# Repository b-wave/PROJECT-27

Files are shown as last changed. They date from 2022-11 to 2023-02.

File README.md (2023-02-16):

# PROJECT-27
Which was a Telemetering transmitter from the 1964 era book **103 Simple Transistor Projects**, by Tom Knitel  I grew up with this book and this was one of my bucket-list projects from it. Although I am *not exactly sure* how my pre-teen self planned to send this device aloft.  I do remember trying to build it up with a CB radio crystal and a few random transistors (it never worked) and had some vague idea of 20 or so toy helium balloons in a laundry bag! Informaton from this transmitter is not sent digitally from this device either.  The RF is AM modulated and the frequency of the modulation is controlled by a thermistor.  Of course, this would need to be calibrated to make any sense of the data. 

For more details on my check out my site: (https://brainwave57.blogspot.com/2022/11/project-27-part-1.html)

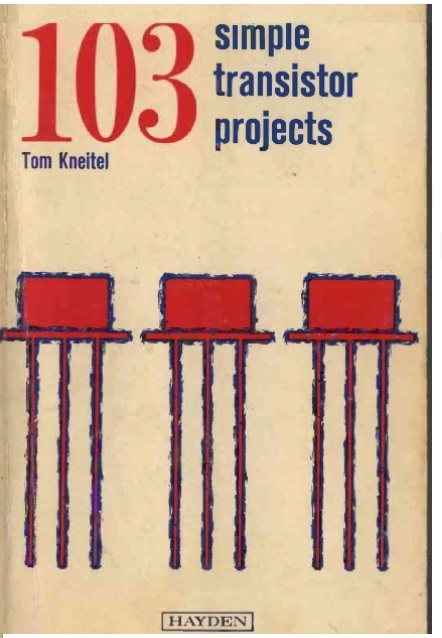
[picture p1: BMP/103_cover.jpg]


103 Projects!

I created two versions, MKI and MKIII are functional. The MK1 is pretty much a copy of the original version. The Mk3 may actually be legal to operate as a telemetering device on the current 27-MHz band. The MK3 is a modern version that also features the same simple Temperature-to-Frequency converter it also now includes a way to include altitude information encoded in the length of the tone burst (Pulse modulated) and even a bright LED beacon.  I thought I had some of the original Ge Transistors, but it turned out they were really old-style Si devices. I found sources for the original transistors online but at a cost that did not make it practical to try or even risk these antique transistors to this experiment... Even buying the Over Tone crystals is costly. I did find a solution for both.  

They are built without any Germanium or PNP transistors. 

The files here are "modern" versions of the **#27 Telemetering Transmitter**. Basically, the first version was a simple crystal oscillator and a multivibrator circuit - just like the original. The crystal was taken from a toy "27MHZ" remote controller. It turns out the frequency is in the ISM telemetry part of that band. The original project #27 goes into detail about the FCC requirements, in force in 1964. He even recommends the transmitter is inspected by a certified person to comply with the then requirements. I did a quick search of the FCC rules and found the mentioned sections are not even in existence. I did see the current requirements have differences are that more power is apparently now allowed - but - there is now a limit now on the length of time a "tone" can be transmitted. The original and MK1 transmit continuously so they would definitely not be legal. But of course, none of these transmitters are FCC type accepted for manufacture but for experimental purposes on the ISM band it should be OK.

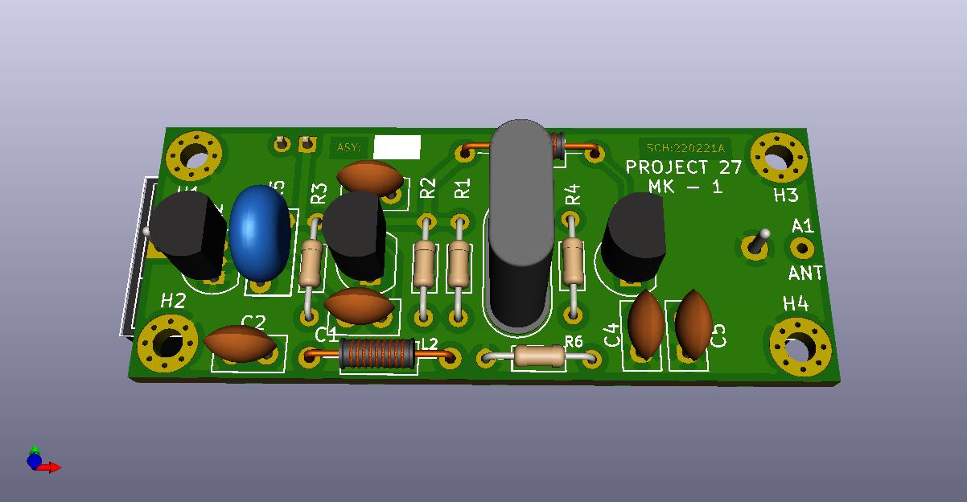
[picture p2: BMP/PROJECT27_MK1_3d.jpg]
PROJECT-27

Telemetering Tranmiter Version MK1 3D View

That's why the new Mk3 version.  It attempts to limit the time that the tone is transmitted and clean up the output to hopefully comply with the rules.  The original seems to rely on low power and the antenna length to limit the spurious emissions surely caused by a 3rd overtone crystal oscillator.  The timing circuit was implemented as another two-transistor multivibrator. Since it originally started life as a "Flashing beacon" in the same book -- I also added a high efficiency LED that produces a bright strobe beacon as well so it can be tracked and possibly help find it.  Since the strobes timing was arbitrarily set, I realized that that could be, in fact, controlled and a second channel of information could be transmitted by this pulse length.  I then constructed a 1960's technology version of an altimeter that is a simple sealed tube of air with a plunger attached to a slide potentiometer. I will add details of this device later. (Mk2 was a never completed high(er) power version)

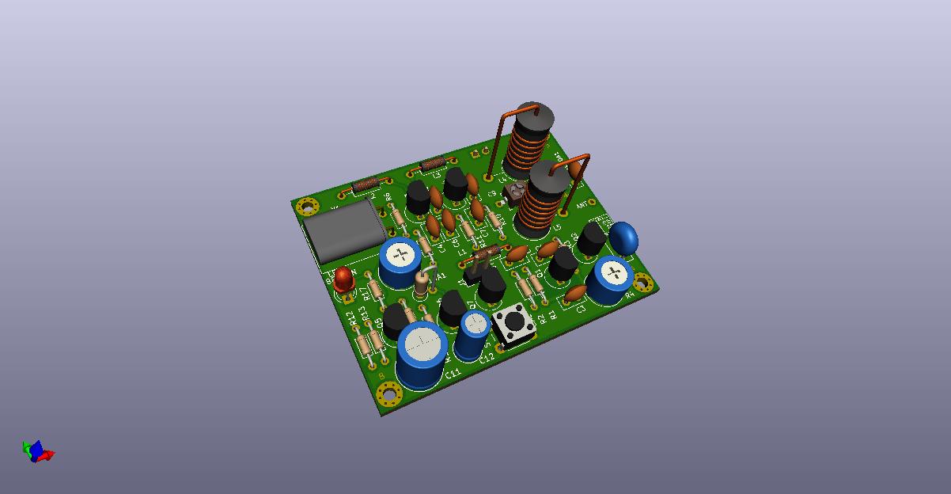
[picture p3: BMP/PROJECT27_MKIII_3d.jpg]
PROJECT-27

Telemetering Tranmitter Version MK3 (Top 3D View)

The original was intended to powered only by 1.5V AA cell.  Three volts would actually be OK for FCC power output requirements. I think a modern LiPo would probably survive the extreme cold a balloon-borne sonde would encounter. There is now plenty of room for two cells as shown on the bottom view. Of course, weight is a prime consideration for balloon payloads as well so LiPo may be best.  

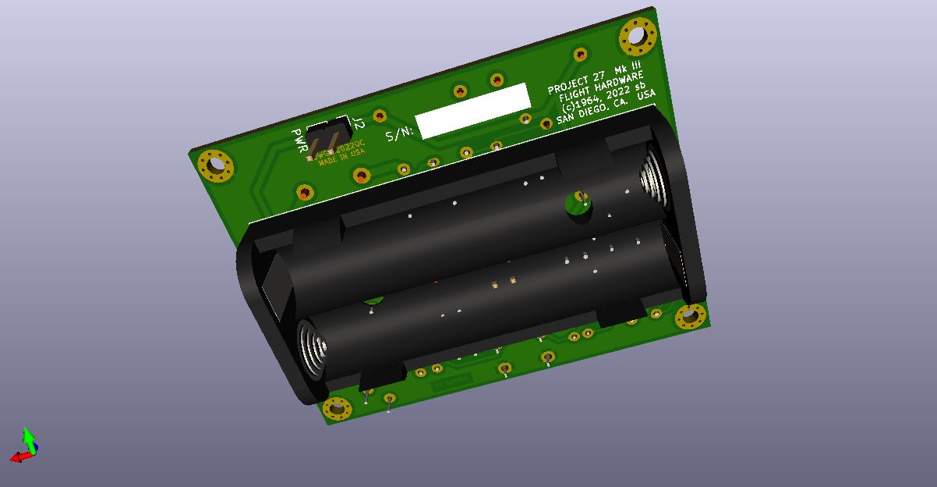
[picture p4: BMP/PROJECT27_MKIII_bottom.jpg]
PROJECT-27

Tranmitter Version MK3 (Bottom 3D View)

I doubt if this thing ever did fly on a balloon to or will my version but it was a fun pandemic project just to see it work. 

#Circuit boards are availble on:

MKI  Board: https://oshpark.com/shared_projects/9dS7OwyD

MKII Board:  **Never Finished** 

MKIII Board: https://oshpark.com/shared_projects/CLHAeEab

Cheers!

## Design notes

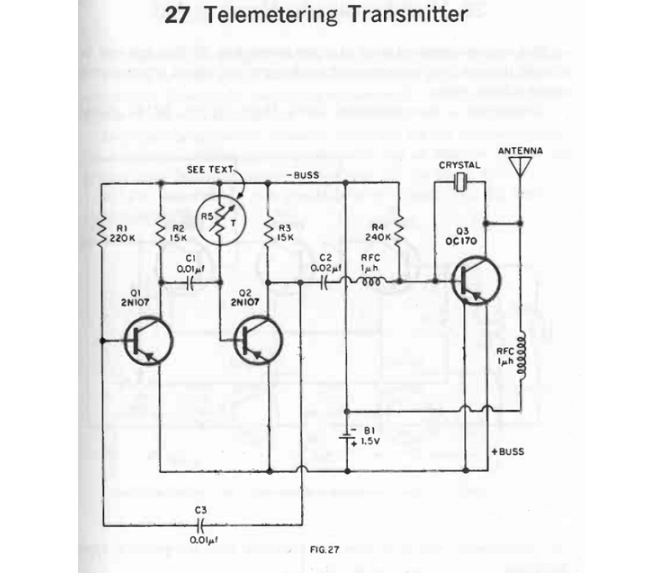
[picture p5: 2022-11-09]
BMP/Proj27_sch.png

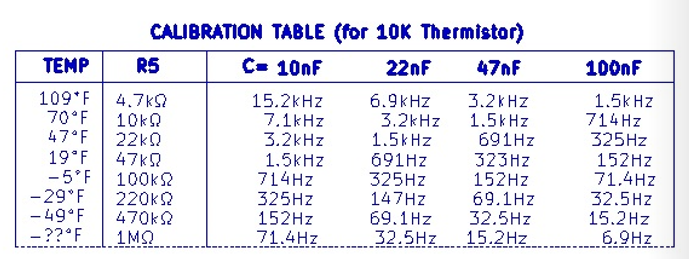
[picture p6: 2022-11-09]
BMP/proj27_cal.png

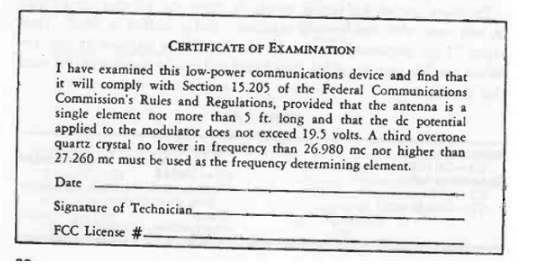
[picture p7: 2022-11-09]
BMP/proj27-cirtif.png

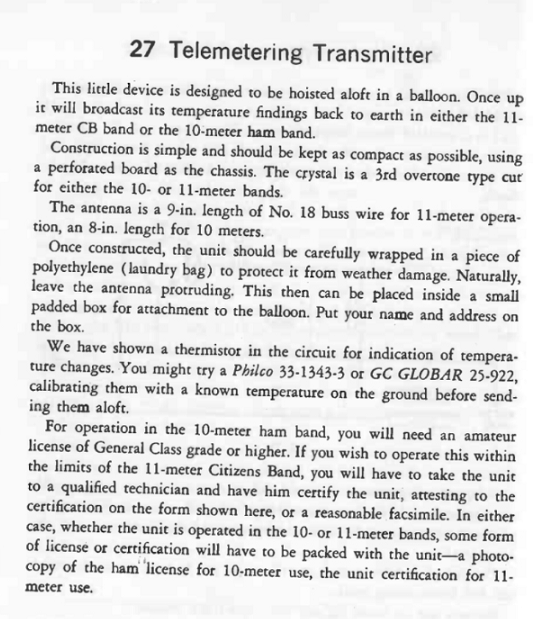
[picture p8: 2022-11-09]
BMP/Proj27_Text.png

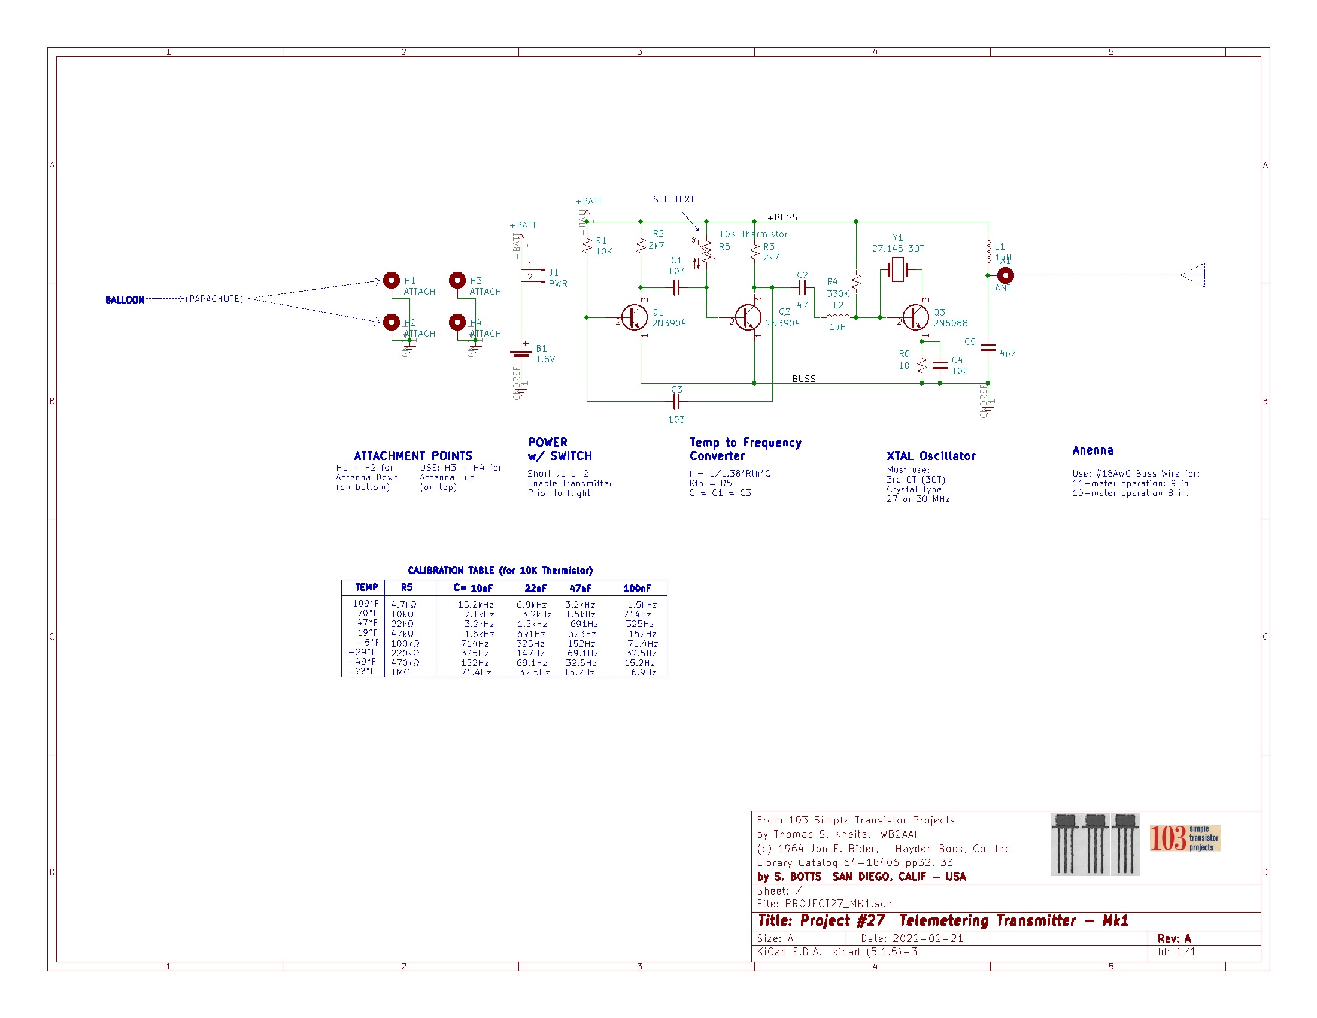
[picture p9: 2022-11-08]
BMP/project27_MK1.jpg

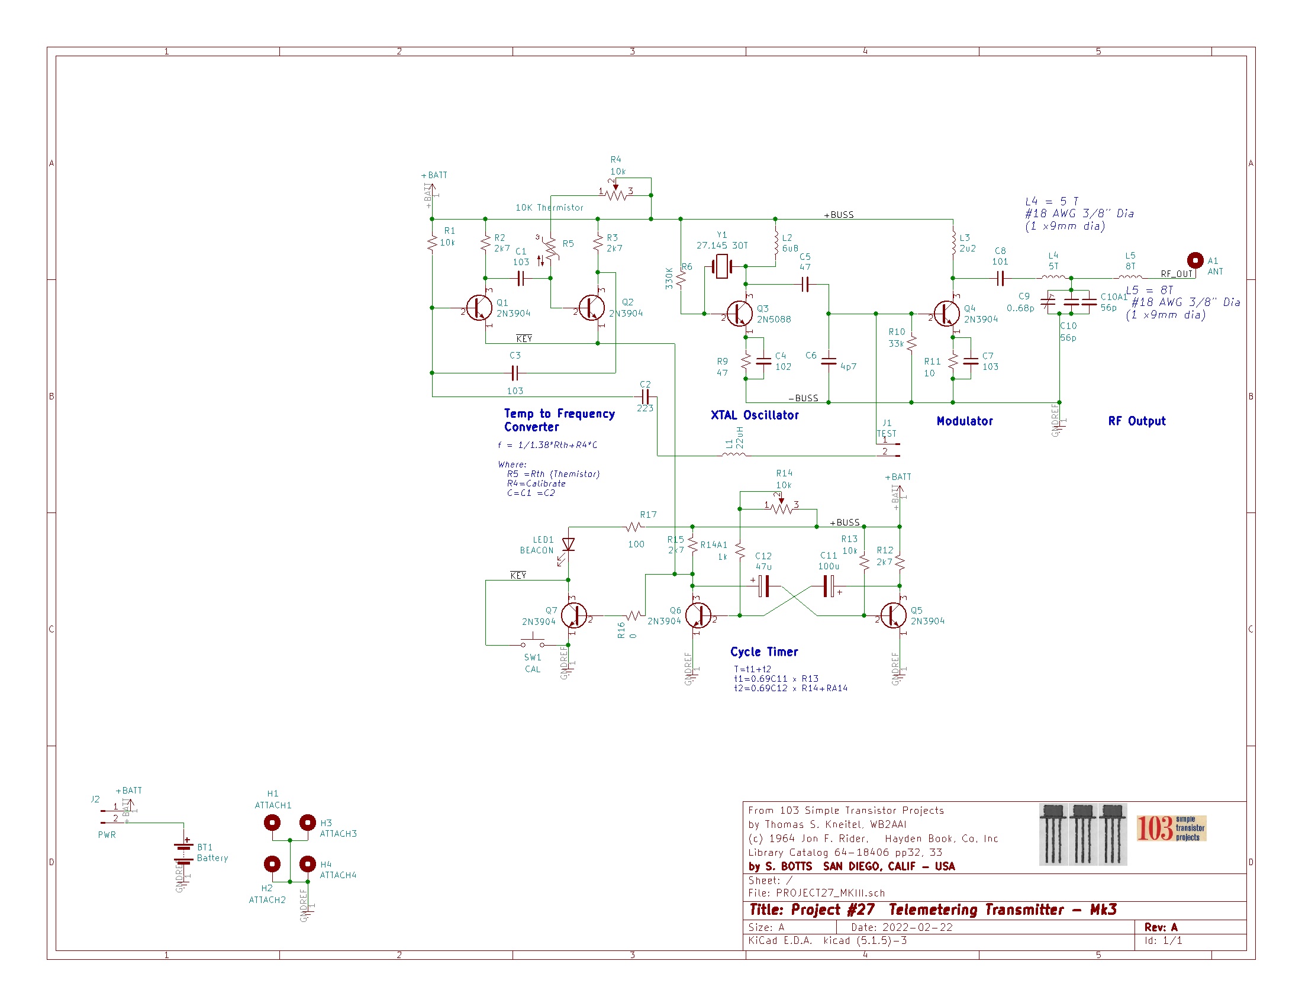
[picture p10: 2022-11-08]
BMP/Project27_MKIII.jpg

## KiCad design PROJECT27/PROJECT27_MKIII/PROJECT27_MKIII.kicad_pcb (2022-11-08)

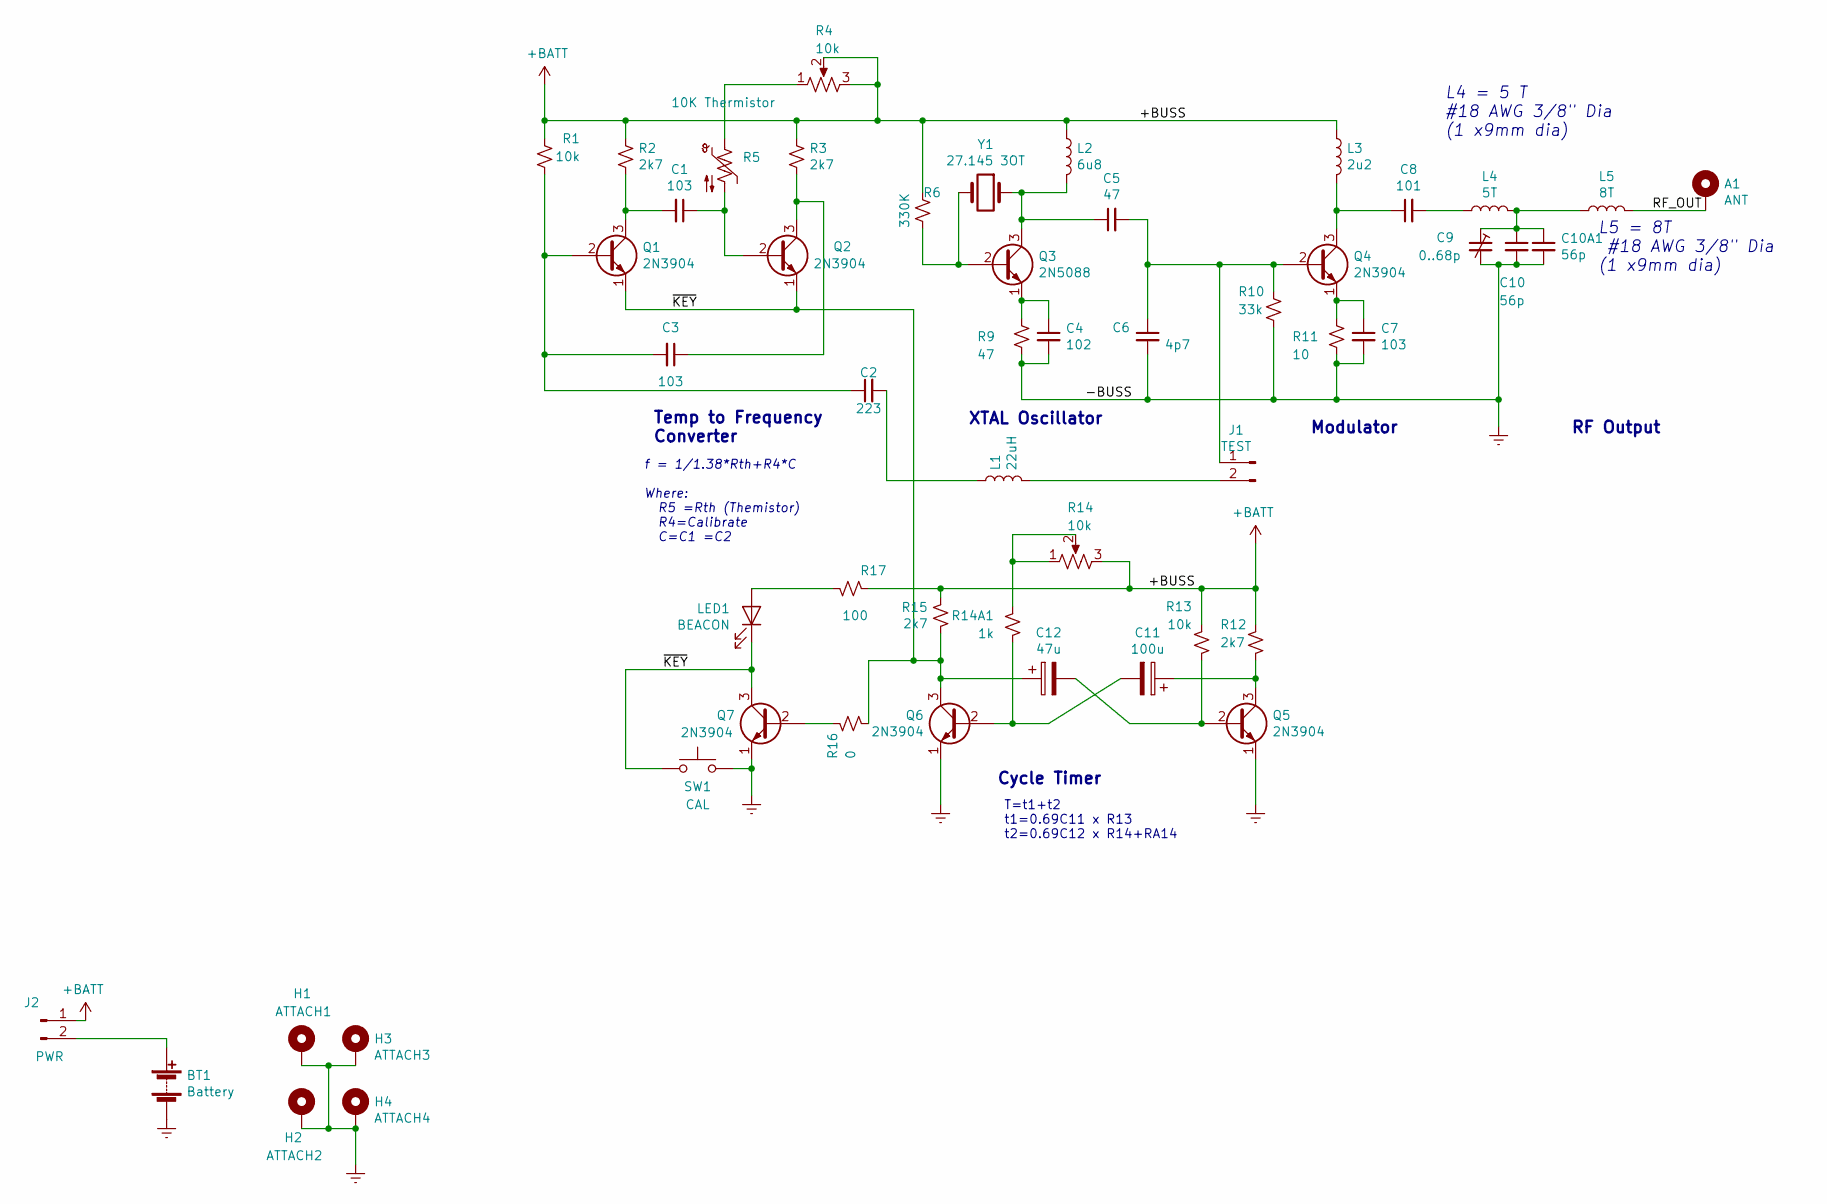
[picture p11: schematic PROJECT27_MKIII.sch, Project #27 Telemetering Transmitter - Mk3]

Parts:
A1: ANT; Hole_100_75
BT1: Battery; BatteryHolder_Keystone_2468_2xAAA
C1, C3, C7: 103; C_Disc_D5.0mm_W2.5mm_P2.50mm
C2: 223; C_Disc_D5.0mm_W2.5mm_P2.50mm
C4: 102; C_Disc_D5.0mm_W2.5mm_P2.50mm
C5: 47; C_Disc_D5.0mm_W2.5mm_P2.50mm
C6: 4p7; C_Disc_D5.0mm_W2.5mm_P2.50mm
C8: 101; C_Disc_D5.0mm_W2.5mm_P2.50mm
C9: 0..68p; C_Trimmer_Murata_TZB4-B
C10, C10A1: 56p; C_Disc_D5.0mm_W2.5mm_P2.50mm
C11: 100u; C_Radial_D8.0mm_H11.5mm_P3.50mm
C12: 47u; C_Radial_D5.0mm_H11.0mm_P2.00mm
H1: ATTACH1; MountingHole_2.2mm_M2_Pad_Via
H2: ATTACH2; MountingHole_2.2mm_M2_Pad_Via
H3: ATTACH3; MountingHole_2.2mm_M2_Pad_Via
H4: ATTACH4; MountingHole_2.2mm_M2_Pad_Via
J1: TEST; PinHeader_1x02_P2.54mm_Vertical
J2: PWR; PinHeader_1x02_P2.54mm_Vertical
L1: 22uH; L_Axial_L5.3mm_D2.2mm_P10.16mm_Horizontal_Vishay_IM-1
L2: 6u8; L_Axial_L5.3mm_D2.2mm_P10.16mm_Horizontal_Vishay_IM-1
L3: 2u2; L_Axial_L5.3mm_D2.2mm_P10.16mm_Horizontal_Vishay_IM-1
L4: 5T; L_Axial_L16.0mm_D7.5mm_P7.62mm_Vertical_Fastron_XHBCC
L5: 8T; L_Axial_L16.0mm_D7.5mm_P7.62mm_Vertical_Fastron_XHBCC
LED1: BEACON; LED_D3.0mm
Q1, Q2, Q4, Q5, Q6, Q7: 2N3904; TO-92_Inline
Q3: 2N5088; TO-92_Inline
R1, R13: 10k; R_Axial_DIN0204_L3.6mm_D1.6mm_P7.62mm_Horizontal
R2, R3, R12, R15: 2k7; R_Axial_DIN0204_L3.6mm_D1.6mm_P7.62mm_Horizontal
R4, R14: 10k; Potentiometer_Bourns_3339P_Vertical_HandSoldering
R5: 10K Thermistor; RV_Disc_D7mm_W3.4mm_P5mm
R6: 330K; R_Axial_DIN0204_L3.6mm_D1.6mm_P7.62mm_Horizontal
R9: 47; R_Axial_DIN0204_L3.6mm_D1.6mm_P7.62mm_Horizontal
R10: 33k; R_Axial_DIN0204_L3.6mm_D1.6mm_P7.62mm_Horizontal
R11: 10; R_Axial_DIN0204_L3.6mm_D1.6mm_P7.62mm_Horizontal
R14A1: 1k; R_Axial_DIN0207_L6.3mm_D2.5mm_P2.54mm_Vertical
R16: 0; R_Axial_DIN0204_L3.6mm_D1.6mm_P7.62mm_Horizontal
R17: 100; R_Axial_DIN0204_L3.6mm_D1.6mm_P7.62mm_Horizontal
SW1: CAL; SW_PUSH_6mm_H4.3mm
Y1: 27.145 3OT; Crystal_HC49-U_Horizontal

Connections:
+BATT: J2.1, L2.1, L3.1, R1.2, R2.1, R3.1, R4.2, R4.3, R6.1, R12.2, R13.1, R14.3, R15.1, R17.1
/RF_OUT: A1.1, L5.2
/~KEY: C12.1, LED1.1 (K), Q1.1 (E), Q2.1 (E), Q6.3 (C), Q7.3 (C), R15.2, R16.1, SW1.2
GNDREF: BT1.2 (-), C4.2, C6.2, C7.2, C9.2, C10.2, C10A1.2, H1.1, H2.1, H3.1, H4.1, Q5.1 (E), Q6.1 (E), Q7.1 (E), R9.2, R10.2, R11.2, SW1.1
unnamed: BT1.1 (+), J2.2
unnamed: C1.1, Q2.2 (B), R5.2
unnamed: C1.2, Q1.3 (C), R2.2
unnamed: C2.1, C3.2, Q1.2 (B), R1.1
unnamed: C2.2, L1.1
unnamed: C3.1, Q2.3 (C), R3.2
unnamed: C4.1, Q3.1 (E), R9.1
unnamed: C5.1, L2.2, Q3.3 (C), Y1.1
unnamed: C5.2, C6.1, J1.1, Q4.2 (B), R10.1
unnamed: C7.1, Q4.1 (E), R11.1
unnamed: C8.1, L3.2, Q4.3 (C)
unnamed: C8.2, L4.2
unnamed: C9.1, C10.1, C10A1.1, L4.1, L5.1
unnamed: C11.1, Q5.3 (C), R12.1
unnamed: C11.2, Q6.2 (B), R14A1.2
unnamed: C12.2, Q5.2 (B), R13.2
unnamed: J1.2, L1.2
unnamed: LED1.2 (A), R17.2
unnamed: Q3.2 (B), R6.2, Y1.2
unnamed: Q7.2 (B), R16.2
unnamed: R4.1, R5.1
unnamed: R14.1, R14.2, R14A1.1

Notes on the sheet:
T=t1+t2 t1=0.69C11 x R13 t2=0.69C12 x R14+RA14
f = 1/1.38*Rth+R4*C Where: R5 =Rth (Themistor) R4=Calibrate C=C1 =C2
Cycle Timer
Temp to Frequency Converter
XTAL Oscillator
RF Output
L4 = 5 T #18 AWG 3/8" Dia (1 x9mm dia)
L5 = 8T #18 AWG 3/8" Dia (1 x9mm dia)
Modulator

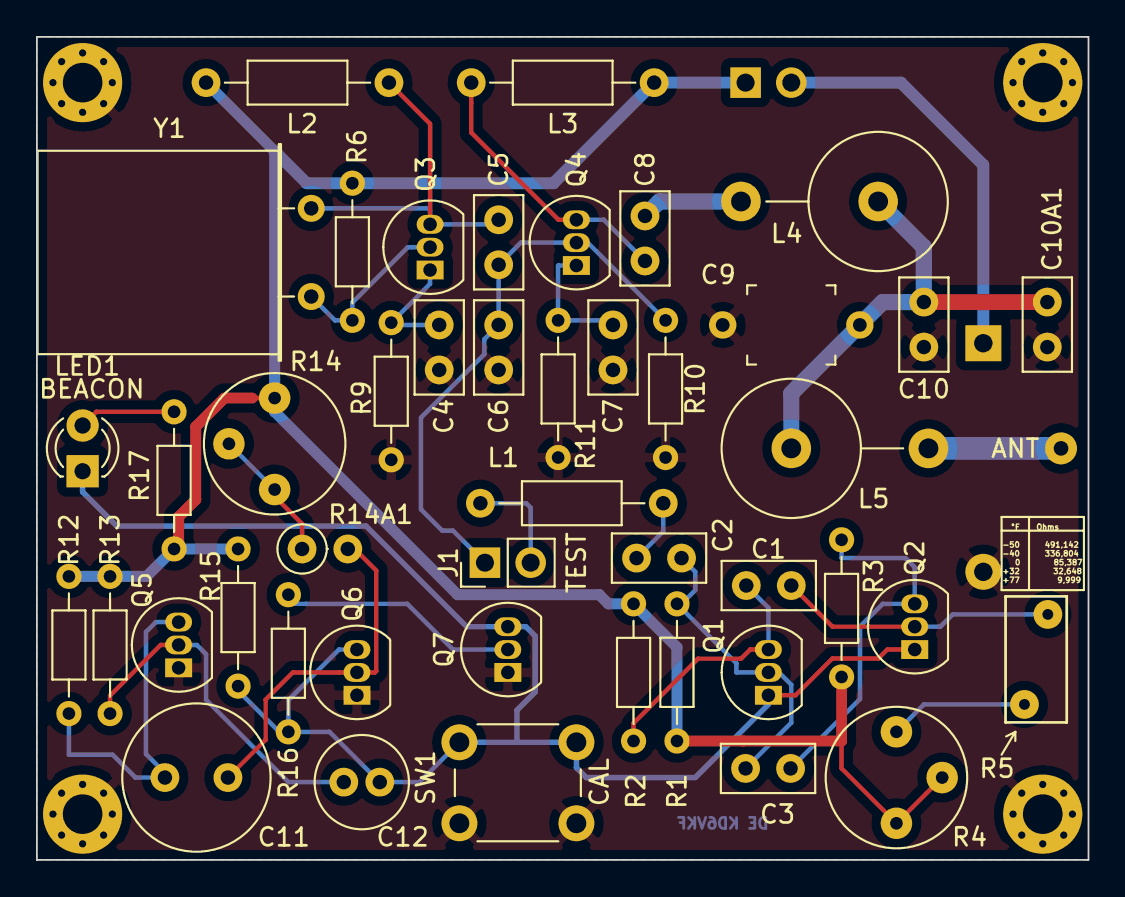
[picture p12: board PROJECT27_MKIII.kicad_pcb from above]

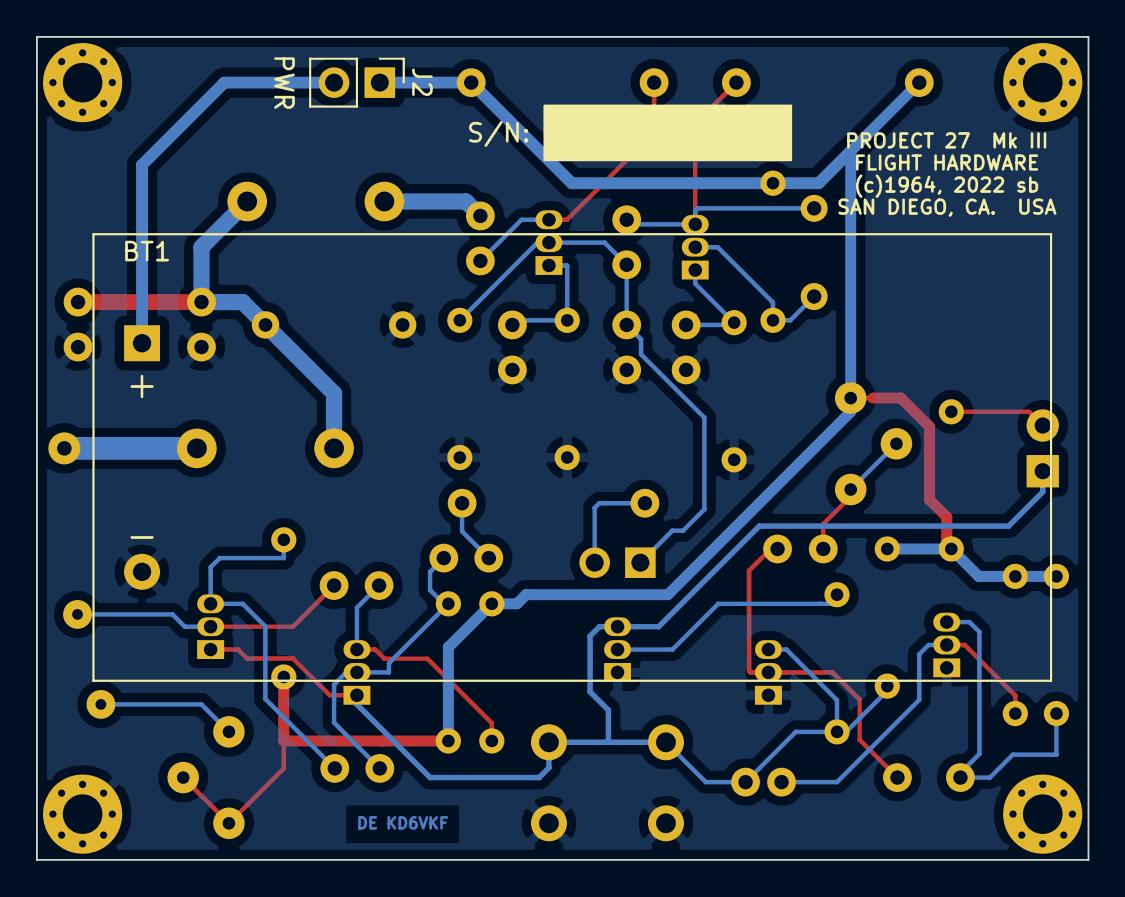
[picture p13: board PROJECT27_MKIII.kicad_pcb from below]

Board: 2 copper layers, 58.4 x 45.7 mm, 52 parts (2 on the bottom side), 26 nets.

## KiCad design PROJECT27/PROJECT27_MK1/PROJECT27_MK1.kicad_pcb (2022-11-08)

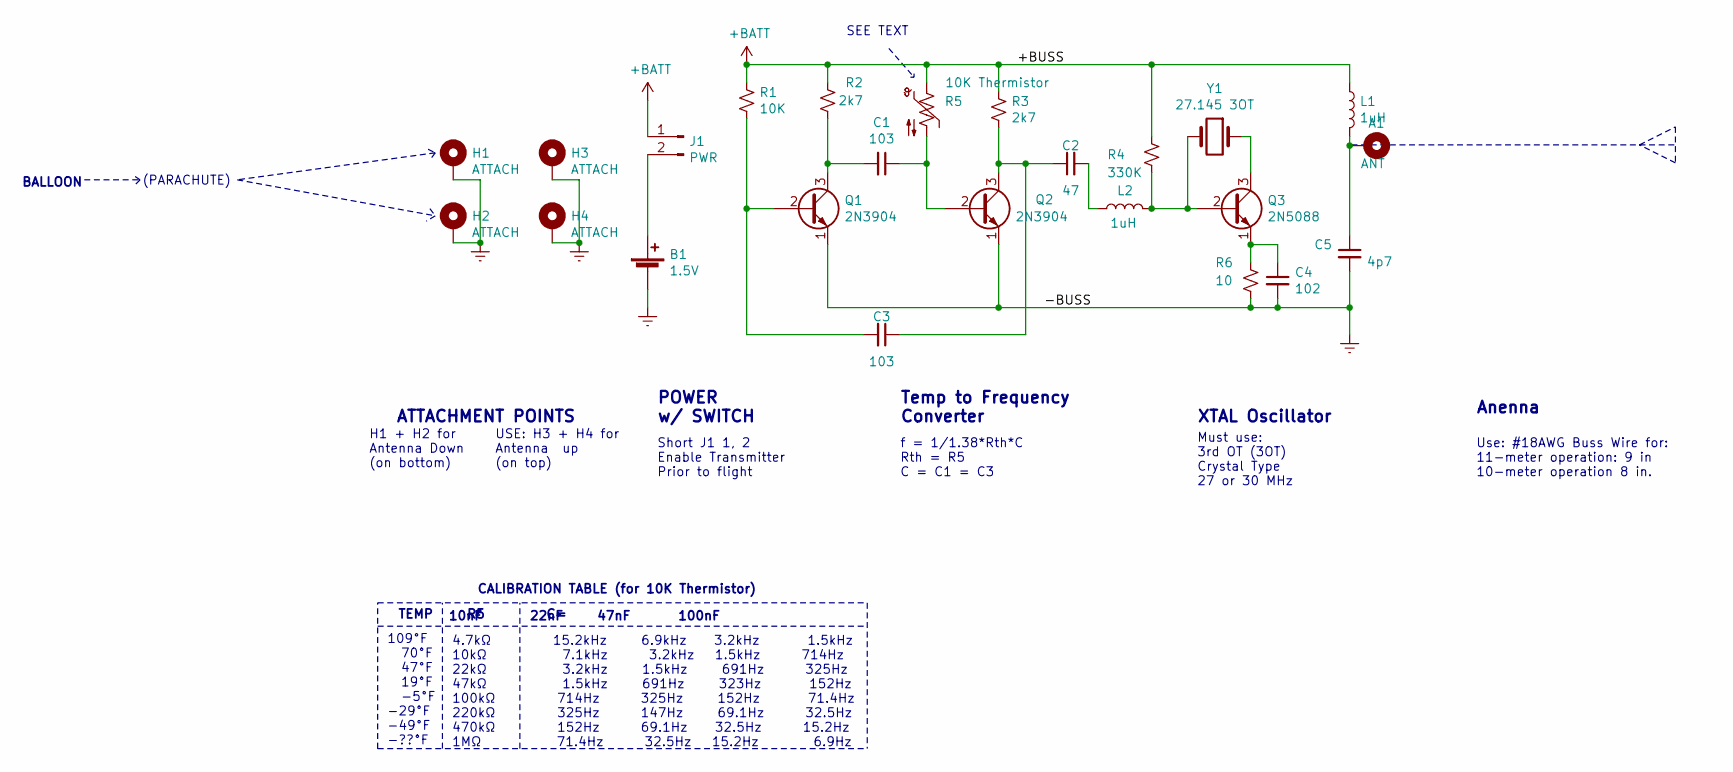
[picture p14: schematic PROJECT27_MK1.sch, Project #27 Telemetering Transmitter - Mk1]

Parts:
A1: ANT; Hole_100_75
B1: 1.5V; BatteryHolder_Keystone_2466_1xAAA
C1, C3: 103; C_Disc_D5.0mm_W2.5mm_P2.50mm
C2: 47; C_Disc_D5.0mm_W2.5mm_P2.50mm
C4: 102; C_Disc_D5.0mm_W2.5mm_P2.50mm
C5: 4p7; C_Disc_D5.0mm_W2.5mm_P2.50mm
H1, H2, H3, H4: ATTACH; MountingHole_2.2mm_M2_Pad_Via
J1: PWR; PinHeader_1x02_P2.00mm_Vertical
L1, L2: 1uH; L_Axial_L5.3mm_D2.2mm_P10.16mm_Horizontal_Vishay_IM-1
Q1, Q2: 2N3904; TO-92_Inline
Q3: 2N5088; TO-92_Inline
R1: 10K; R_Axial_DIN0204_L3.6mm_D1.6mm_P7.62mm_Horizontal
R2, R3: 2k7; R_Axial_DIN0204_L3.6mm_D1.6mm_P7.62mm_Horizontal
R4: 330K; R_Axial_DIN0204_L3.6mm_D1.6mm_P7.62mm_Horizontal
R5: 10K Thermistor; RV_Disc_D7mm_W3.4mm_P5mm
R6: 10; R_Axial_DIN0204_L3.6mm_D1.6mm_P7.62mm_Horizontal
Y1: 27.145 3OT; Crystal_HC49-U_Vertical

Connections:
+BATT: J1.1, L1.1, R1.1, R2.2, R3.1, R4.1, R5.1
GNDREF: B1.2 (-), C4.2, C5.2, H1.1, H2.1, H3.1, H4.1, Q1.1 (E), Q2.1 (E), R6.2
unnamed: A1.1, C5.1, L1.2
unnamed: B1.1 (+), J1.2
unnamed: C1.1, Q2.2 (B), R5.2
unnamed: C1.2, Q1.3 (C), R2.1
unnamed: C2.1, C3.1, Q2.3 (C), R3.2
unnamed: C2.2, L2.1
unnamed: C3.2, Q1.2 (B), R1.2
unnamed: C4.1, Q3.1 (E), R6.1
unnamed: L2.2, Q3.2 (B), R4.2, Y1.2
unnamed: Q3.3 (C), Y1.1

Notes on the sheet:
f = 1/1.38*Rth*C Rth = R5 C = C1 = C3
Temp to Frequency Converter
XTAL Oscillator
(PARACHUTE)
SEE TEXT
ATTACHMENT POINTS
BALLOON
POWER w/ SWITCH
H1 + H2 for Antenna Down (on bottom)
USE: H3 + H4 for Antenna up (on top)
Short J1 1, 2 Enable Transmitter Prior to flight
Must use: 3rd OT (3OT) Crystal Type 27 or 30 MHz
Anenna
Use: #18AWG Buss Wire for: 11-meter operation: 9 in 10-meter operation 8 in.
4.7kΩ 15.2kHz 6.9kHz 3.2kHz 1.5kHz 10kΩ 7.1kHz 3.2kHz 1.5kHz 714Hz 22kΩ 3.2kHz 1.5kHz 691Hz 325Hz 47kΩ 1.5kHz 691Hz 323Hz 152Hz 100kΩ 714Hz 325Hz 152Hz 71.4Hz 220kΩ 325Hz 147Hz 69.1Hz 32.5Hz 470kΩ 152Hz 69.1Hz 32.5Hz 15.2Hz 1MΩ 71.4Hz 32.5Hz 15.2Hz 6.9Hz
109°F 70°F 47°F 19°F -5°F -29°F -49°F -??°F
TEMP R5 C=
CALIBRATION TABLE (for 10K Thermistor)
10nF 22nF 47nF 100nF

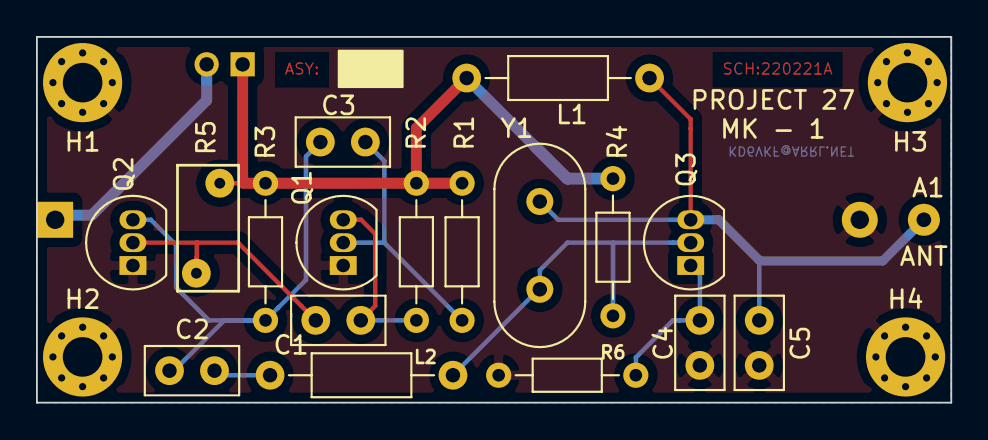
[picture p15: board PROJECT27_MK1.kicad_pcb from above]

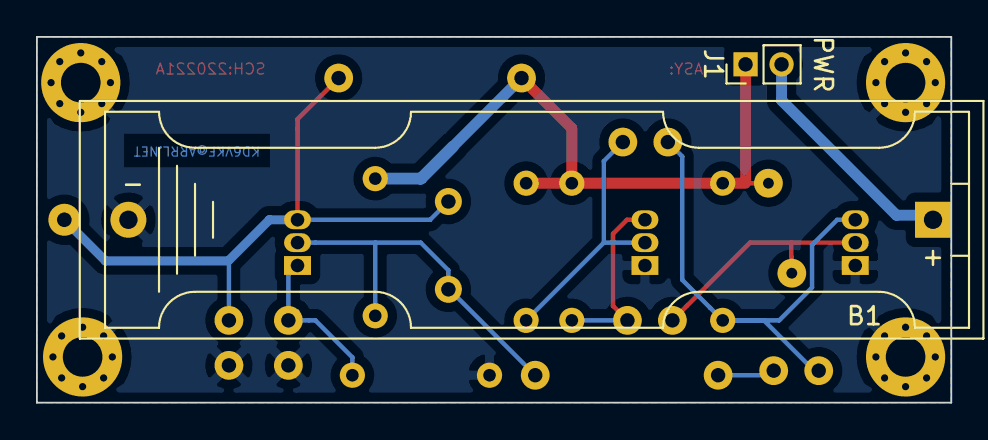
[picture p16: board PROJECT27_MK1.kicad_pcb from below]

Board: 2 copper layers, 50.8 x 20.3 mm, 24 parts (2 on the bottom side), 12 nets.

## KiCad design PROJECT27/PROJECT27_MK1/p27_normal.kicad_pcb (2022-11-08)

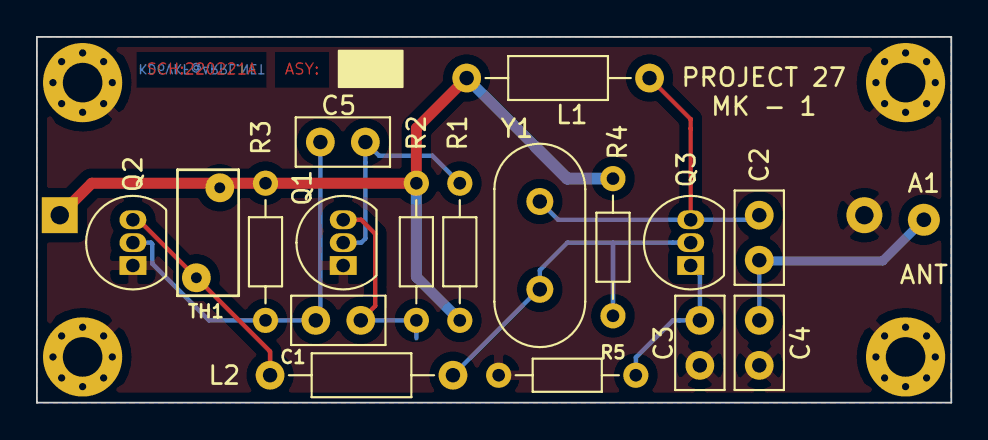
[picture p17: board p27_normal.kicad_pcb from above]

Board: 2 copper layers, 50.8 x 20.3 mm, 23 parts (1 on the bottom side), 10 nets.

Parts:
A1: ANT; Hole_100_75
BT1: Battery_Cell; BatteryHolder_Keystone_2466_1xAAA
C1, C5: 103; C_Disc_D5.0mm_W2.5mm_P2.50mm
C2: 47; C_Disc_D5.0mm_W2.5mm_P2.50mm
C3: 102; C_Disc_D5.0mm_W2.5mm_P2.50mm
C4: 4p7; C_Disc_D5.0mm_W2.5mm_P2.50mm
H1, H2, H3, H4: MountingHole_Pad; MountingHole_2.2mm_M2_Pad_Via
L1, L2: 1uH; L_Axial_L5.3mm_D2.2mm_P10.16mm_Horizontal_Vishay_IM-1
Q1, Q2: 2N3904; TO-92_Inline
Q3: 2N5088; TO-92_Inline
R1, R3: 2k7; R_Axial_DIN0204_L3.6mm_D1.6mm_P7.62mm_Horizontal
R2: 10k; R_Axial_DIN0204_L3.6mm_D1.6mm_P7.62mm_Horizontal
R4: 330K; R_Axial_DIN0204_L3.6mm_D1.6mm_P7.62mm_Horizontal
R5: 55; R_Axial_DIN0204_L3.6mm_D1.6mm_P7.62mm_Horizontal
TH1: 10K PTC; RV_Disc_D7mm_W3.4mm_P5mm
Y1: 27.145 3OT; Crystal_HC49-U_Vertical

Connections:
+BATT: BT1.1, L1.1, R1.1, R2.2, R3.1, R4.1, TH1.1
GNDREF: BT1.2, C3.2, C4.2, H1.1, H2.1, H3.1, H4.1, Q1.1, Q2.1, R5.2
unnamed: A1.1, C2.2, C4.1
unnamed: C1.1, C5.1, Q2.2, R3.2
unnamed: C1.2, Q1.3, R2.1
unnamed: C2.1, L1.2, Q3.3, Y1.1
unnamed: C3.1, Q3.1, R5.1
unnamed: C5.2, Q1.2, R1.2
unnamed: L2.1, Q2.3, TH1.2
unnamed: L2.2, Q3.2, R4.2, Y1.2

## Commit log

2022-11-09 Delete PROJECT27 directory
    clean up directory
    [PROJECT27_MK1.kicad_pcb, PROJECT27_MK1.sch, PROJECT27_MKII.kicad_pcb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]
2022-11-09 Add files via upload
    to clean up directory
    [PROJECT27_MK1.kicad_pcb, PROJECT27_MK1.sch, PROJECT27_MKIII.kicad_pcb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]
2023-02-15 Update README.md
    added OSH Park url for Circuit boards
2023-02-15 Update README.md
    OSH Park Board files

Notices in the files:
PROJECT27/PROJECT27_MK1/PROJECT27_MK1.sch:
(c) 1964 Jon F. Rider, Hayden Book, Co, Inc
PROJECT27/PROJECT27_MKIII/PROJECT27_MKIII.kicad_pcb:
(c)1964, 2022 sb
